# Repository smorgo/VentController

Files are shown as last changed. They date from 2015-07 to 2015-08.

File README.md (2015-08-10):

# VentController
<p>Code and hardware resources for my IoT Vent Controller, intended to control automatic conservatory roof vents (but equally applicable to many similar use cases).</p>
<p>The system is based around the ESP8266 microcontroller. I'm currently using it in its SparkFun ESP8266 Thing guise, but the board could be reworked to suit any of the ESP12-derived boards out there.</p>
<p>You can find the Eagle schematic and board files in the Eagle folder.</p>
<p>Initially, I had intended to use the NodeMCU firmware for the ESP8266. However, that simply takes too much memory and caused immense frustration, so I've moved to using the Arduino IDE and programming in C++. The NodeMCU source files are just here for reference.</p>

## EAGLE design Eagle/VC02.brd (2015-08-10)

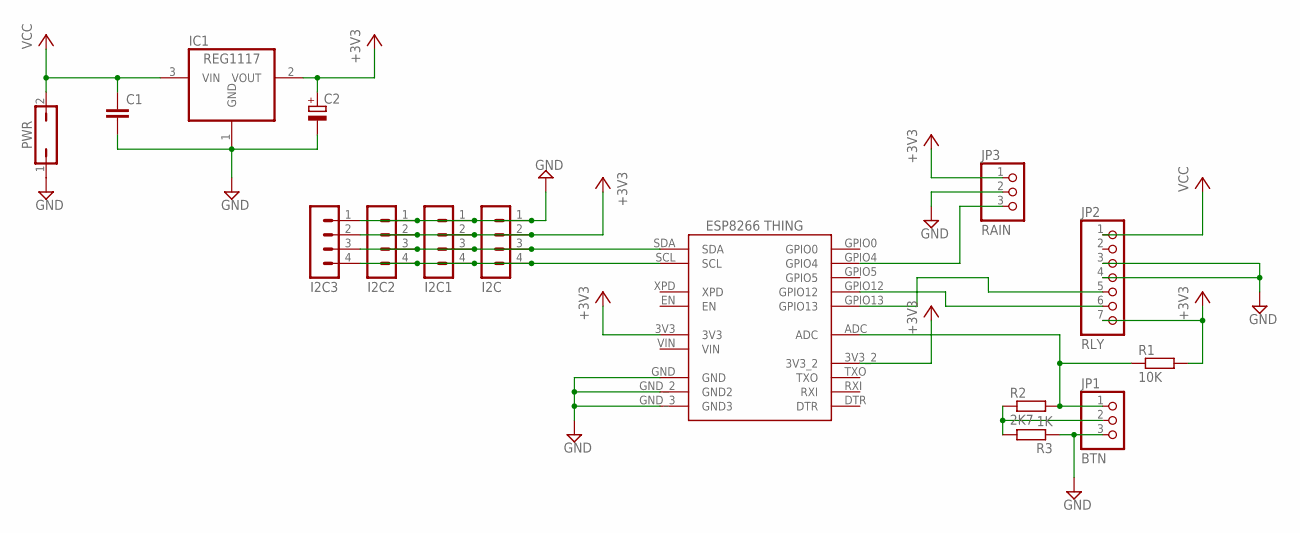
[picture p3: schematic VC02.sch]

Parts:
C1: C-EUC0603K; C0603K; MPN 0603YC104K4T2A
C2: CPOL-EUB; PANASONIC_B; MPN EEEFC1C220AR
I2C, I2C1, I2C2, I2C3: MA04-1
IC1: REG1117; SOT223; MPN LD1117S33TR
JP1: BTN; 1X03
JP2: RLY; 1X07
JP3: RAIN; 1X03
PWR: JP1Q; JP1; MPN 640452-2
R1: 10K; R0805; MPN CRCW080510K0FKEA
R2: 2K7; R0805; MPN CRCW08052K70FKEA
R3: 1K; R0805; MPN CRCW08051K00FKEA
U$1: ESP8266_THING

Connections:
+3V3: C2.+, I2C.2, I2C1.2, I2C2.2, I2C3.2, IC1.2 (VOUT), JP2.7, JP3.1, R1.2, U$1.3V3, U$1.3V3_2
GND: C1.2, C2.-, I2C.1, I2C1.1, I2C2.1, I2C3.1, IC1.1 (GND), JP1.3, JP2.3, JP2.4, JP3.2, PWR.1, R3.1, U$1.GND, U$1.GND_2 (GND2), U$1.GND_3 (GND3)
unnamed: JP2.6, U$1.GPIO12
unnamed: JP2.5, U$1.GPIO13
unnamed: JP3.3, U$1.GPIO4
unnamed: JP1.2, R2.1, R3.2
unnamed: JP1.1, R1.1, R2.2, U$1.ADC
unnamed: I2C.4, I2C1.4, I2C2.4, I2C3.4, U$1.SCL
unnamed: I2C.3, I2C1.3, I2C2.3, I2C3.3, U$1.SDA
VCC: C1.1, IC1.3 (VIN), JP2.1, PWR.2
VIN: U$1.VIN

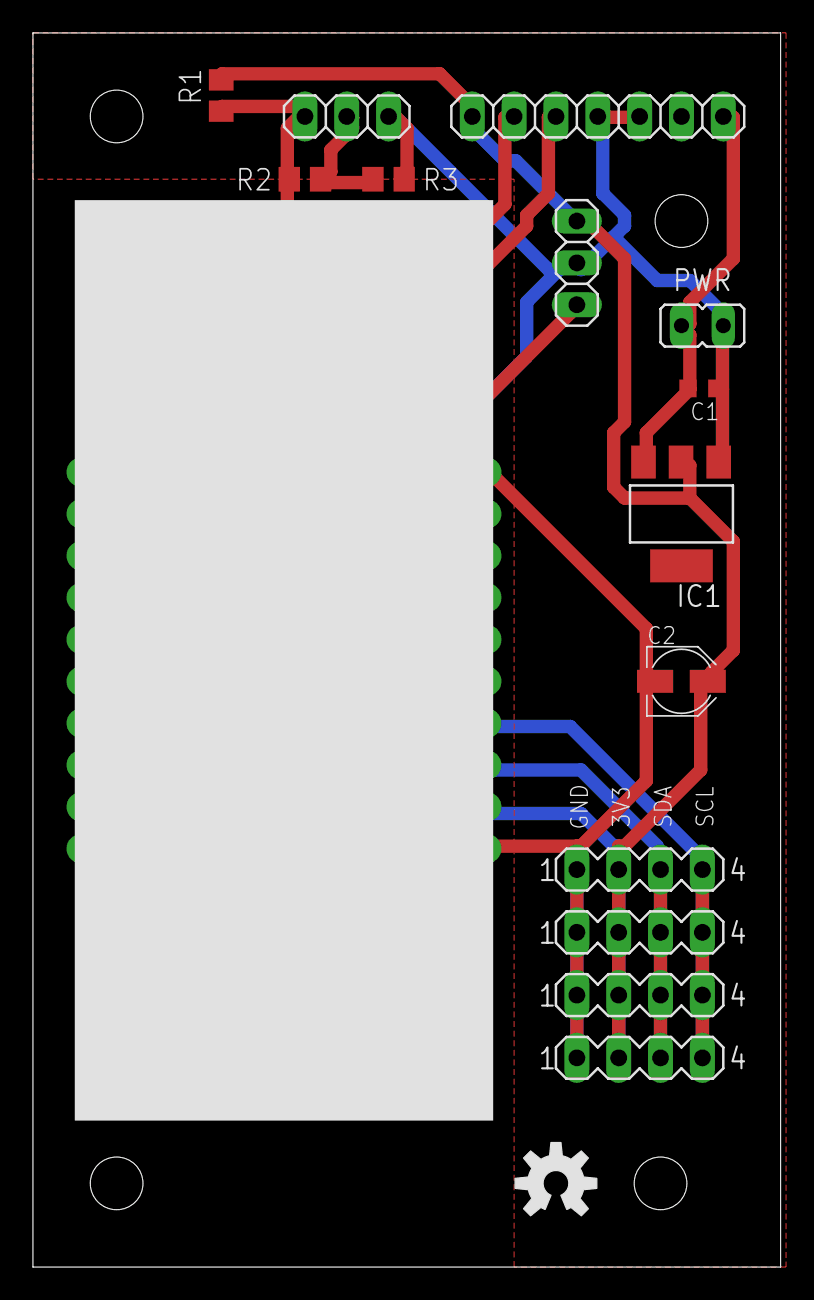
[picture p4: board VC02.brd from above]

Board: 2 copper layers, 45.4 x 74.9 mm, 16 parts (0 on the bottom side), 10 nets.

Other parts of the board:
U$2: OSHW-LOGO-M

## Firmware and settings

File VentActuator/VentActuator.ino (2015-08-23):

/*
 * My keys.h file is loaded from a library, so that these sensitive values
 * are kept outside of the publicly-available code. It should look something
 * like this:
 * 
 * #ifndef __KEYS_H__
 * #define __KEYS_H__
 * #define WIFI_SSID "<Your WiFi SSID>"
 * #define WIFI_PWD "<Your WiFi Passkey>"
 * #define SENSORS_TOPIC "/sensors"
 * #define SENSORS_CMD_TOPIC "/senscmd"
 * #define SERVER "<Your MQTT broker URL or IP address>"
 * #define SENSORS_CLIENT_NAME "SENSORS1"
 * // This secret API_KEY will be shared with other devices that will
 * // publish messages to this device or subscribe to messages from it.
 * // It's used to validate the integrity of the message.
 * #define API_KEY "<32-digit hexadecimal secret key>"
 * #define API_KEY_LENGTH (32)
 * #endif
 */

// Messages received will be processed, even if the hash 
// is incorrect when IS_TEST_MODE is true.
#define IS_TEST_MODE true

#include <keys.h>
#include <MD5.h>
#include <MQTT.h>
#include <PubSubClient.h>

#include <ESP8266WiFi.h>
#include <Wire.h>


// MQTT Topics
const char TOPIC_CMD[] ="/cmd";
const char TOPIC_STATUS[] = "/status";
const char TOPIC_EVENT[] = "/event";

// Message Types
#define MSG_TYPE_SURVEY (1)
#define MSG_TYPE_HELLO (2)
#define MSG_TYPE_SENSOR (3)
#define MSG_TYPE_ACTUATOR (4)
#define MSG_TYPE_ACTSTAT (5)
#define MSG_TYPE_RESET (6)
#define MSG_TYPE_OVERRIDE (7)
#define MSG_TYPE_BUTTON (8)

//////////////////////
// WiFi Definitions //
//////////////////////
const char ssid[] = WIFI_SSID;
const char password[] = WIFI_PWD;
const char server[] = SERVER;
const char clientName[] = ACTUATOR_CLIENT_NAME;
const char apiKey[] = API_KEY;
const int apiKeyLength = API_KEY_LENGTH;
String privateCmdTopic;

#pragma message("ssid: " WIFI_SSID)
#pragma message("server: " SERVER)
#pragma message("clientName: " ACTUATOR_CLIENT_NAME)
#pragma message("apiKey: " API_KEY)

WiFiClient wifiClient;
PubSubClient client(wifiClient, server, 1883);
bool seeded = false;

/////////////////////
// Pin Definitions //
/////////////////////
const int LED_PIN = 5; // Thing's onboard, green LED
const int RAIN_PIN = 4;
const int BUTTON_PIN = A0; 
const int MOTOR_OPEN_PIN = 12;
const int MOTOR_CLOSE_PIN = 13;

/////////////////
// Post Timing //
/////////////////
const unsigned long postRate = 15000;
unsigned long lastPost = 0;
unsigned long counter = 0;

/////////////////
// State       //
/////////////////
const int VENT_CLOSED = 0;
const int VENT_OPEN = 4;
const int NONE = -1;
const int fullTransitTime = 8000; // 8 seconds
const int stepTransitTime = fullTransitTime / VENT_OPEN;
const int WET = 0;
const int DRY = 1;
const int BTN_NONE = 0;
const int BTN_1 = 1;
const int BTN_2 = 2;
const int BTN_BOTH = 3;

// Button thresholds
const int BUTTON_HIGH_THRESHOLD = 840;
const int BUTTON1_HIGH_THRESHOLD = 520;
const int BUTTON2_HIGH_THRESHOLD = 150;

int currentPosition = VENT_OPEN; // On boot, we'll assume it's open and close it.
int targetPosition = NONE;
int newPosition = NONE; // If it's raining, this is zero, otherwise, it's targetPosition
int buttonState = NONE;
int rainState = NONE;
int rainStateCounter = 0;
int previousRainState = NONE;
int previousButtonState = NONE;
int buttonStateCounter = 0;

unsigned long startMillis = 0; // When the current movement started
unsigned long endMillis = 0; // When the current movement should end

bool isMoving = false;
bool directionOpen = false;
bool currentOpenRelayState = HIGH;
bool currentCloseRelayState = HIGH;
bool ignoreRainSensor = false;

String getParam(String msg, String name)
{
  String tmpMsg = "," + msg;
  String lookFor = "," + name + "(";

  int startIx = tmpMsg.indexOf(lookFor);
  if(startIx < 0)
  {
    return "";
  }
  int endIx = tmpMsg.indexOf(")", startIx);
  if(endIx < startIx)
  {
    return "";
  }
  String val =  msg.substring(startIx + lookFor.length()-1, endIx-1);
  Serial.print("Looked for ");
  Serial.print(lookFor);
  Serial.print(" found ");
  Serial.println(val);

  return val;
}

String getHash(String payload)
{
  int payloadLength = payload.length();
  int bufferLength = apiKeyLength + payloadLength + 1;
  char *buffer = (char *)malloc(bufferLength);
  memcpy(buffer, apiKey, apiKeyLength);
  payload.toCharArray(buffer + apiKeyLength, payloadLength + 1);
  
  unsigned char* hash=MD5::make_hash(buffer);
  char *md5str = MD5::make_digest(hash, 16);
  String calcHash = String(md5str);
  free(md5str);
  free(hash);
  free(buffer);

  return calcHash;
}

void processPositionMessage(String msg)
{
  int pos = getParam(msg,"TPOS").toInt();

  Serial.print("Position requested: ");
  Serial.println(pos);
  
  setPosition(pos);
}

bool isMyTopic(String topic)
{
  return (topic == TOPIC_CMD) ||
         (topic == privateCmdTopic);
}

void processMessage(String recv_topic, String msg)
{
  Serial.print(recv_topic);
  Serial.print(" => ");
  Serial.println(msg);

  if(!isMyTopic(recv_topic))
  {
    return;
  }
  
  int msgType = getParam(msg,"M").toInt();

  switch(msgType)
  {
    case MSG_TYPE_SURVEY:
      publish(TOPIC_STATUS,getHelloMessage());
      break;
    case MSG_TYPE_RESET:
      Serial.println("Restarting...");
      delay(1000);
      ESP.restart();
      break;
    case MSG_TYPE_ACTUATOR:
      processPositionMessage(msg);
      break;
    default:
      Serial.println("Unrecognised message");
  }
}

String getValidMessage(String msg)
{
 int delimIx = msg.indexOf(':');

  if(delimIx < 0 || delimIx == (msg.length() - 1))
  {
    // No hash
    return IS_TEST_MODE ? msg : String();
  }

  String payload = msg.substring(0,delimIx);
  String payloadHash = msg.substring(delimIx + 1);

  String calcHash = getHash(payload);
    
  if(calcHash.equalsIgnoreCase(payloadHash))
  {
    Serial.println("HASH MATCH");
    return payload;    
  }

  Serial.println("**HASH DOESN'T MATCH**");
  if(IS_TEST_MODE)
  {
    Serial.print("Received ");
    Serial.println(payloadHash);
    Serial.print("Calculated ");
    Serial.println(calcHash);
    return payload;
  }

  return String();
}

void subscribe(String topic)
{
  Serial.print("Subscribing to MQTT topic: ");
  Serial.println(topic);
  client.subscribe(topic);
}

void publishToConnection(String topic, String msg)
{
  String calcHash = getHash(msg);
  
  msg += ":";
  msg += calcHash;

  Serial.print("[");
  Serial.print(++counter);
  Serial.print("] ");
  Serial.print("Publish to ");
  Serial.print(topic);
  Serial.print(" = ");
  Serial.println(msg);
  
  if(!client.publish(topic, msg))
  {
    Serial.println("Publish FAILED");
  } 
}

void publish(String topic, String msg)
{
  bool connected = client.connected();

  if(!connected) 
  {
    connected = connectBroker();
  }
  
  if(connected)
  {
    publishToConnection(topic, msg);
  }
}

String getBaseMessage(int messageType)
{
  // Add a random value to our message, so that the MD5 hash will be different,
  // even when all of the sensor readings are the same.
  if(!seeded)
  {
    randomSeed(millis());
    seeded = true;
  }
  
  long rand = random(2147483647);
  
  String msg = "R(" + String(rand) + "),M(" + String(messageType) + "),DEV(" + clientName + ")";

  return msg;
}

String getHelloMessage()
{
  String msg = getBaseMessage(MSG_TYPE_HELLO);

  // Add Topics
  msg += ",PUB(" + String(TOPIC_STATUS) + ")" +
         ",SUB(" + String(TOPIC_CMD) + ")" +
         ",SUB(" + privateCmdTopic + ")";

  return msg;
}

String getActStatMessage()
{
  String msg = getBaseMessage(MSG_TYPE_ACTSTAT);

  String msg2 = ",POS(" + String(currentPosition) + "),TPOS(" + String(targetPosition) + "),BN(" + String(buttonState) + "),RA(" + String(rainState) + ")";

  return msg + msg2;
}

String getButtonMessage()
{
  String msg = getBaseMessage(MSG_TYPE_BUTTON);

  String msg2 = ",BN(" + String(buttonState) + ")";

  return msg + msg2;
}

bool connectBroker()
{
  Serial.println("Connecting to MQTT broker");
  if (client.connect(clientName)) 
  {
    Serial.println("Connected to MQTT broker");
    subscribe(TOPIC_CMD);
    subscribe(privateCmdTopic);
    publishToConnection(TOPIC_STATUS,getHelloMessage());
    return true;
  }    
  else 
  {
    Serial.println("MQTT connect failed");
    Serial.println("Will reset and try again...");
    return false;
  }
}

void connectWiFi()
{
  byte ledStatus = LOW;

  Serial.println("Connecting to WiFi");
  // Set WiFi mode to station (as opposed to AP or AP_STA)
  WiFi.mode(WIFI_STA);

  // WiFI.begin([ssid], [passkey]) initiates a WiFI connection
  // to the stated [ssid], using the [passkey] as a WPA, WPA2,
  // or WEP passphrase.
  WiFi.begin(ssid, password);

  // Use the WiFi.status() function to check if the ESP8266
  // is connected to a WiFi network.
  while (WiFi.status() != WL_CONNECTED)
  {
    // Blink the LED
    digitalWrite(LED_PIN, ledStatus); // Write LED high/low
    ledStatus = (ledStatus == HIGH) ? LOW : HIGH;

    // Delays allow the ESP8266 to perform critical tasks
    // defined outside of the sketch. These tasks include
    // setting up, and maintaining, a WiFi connection.
    delay(100);
    // Potentially infinite loops are generally dangerous.
    // Add delays -- allowing the processor to perform other
    // tasks -- wherever possible.
  }
  Serial.println("Connected to WiFi");

  connectBroker();
}

void initHardware()
{
  Serial.begin(9600);
  Serial.println("");
  pinMode(LED_PIN, OUTPUT);
  pinMode(MOTOR_OPEN_PIN, OUTPUT);
  pinMode(MOTOR_CLOSE_PIN, OUTPUT);
  pinMode(RAIN_PIN, INPUT_PULLUP);
  pinMode(BUTTON_PIN, INPUT);
  digitalWrite(LED_PIN, LOW);
  digitalWrite(MOTOR_OPEN_PIN, HIGH);
  digitalWrite(MOTOR_CLOSE_PIN, HIGH);
  Serial.println("");
}

int postStatus()
{
  // LED turns on when we enter, it'll go off when we 
  // successfully post.
  digitalWrite(LED_PIN, HIGH);

  if(IS_TEST_MODE) Serial.println("Publishing status");
   
  if(WiFi.status() != WL_CONNECTED)
  {
    connectWiFi();
  }

  publish(TOPIC_STATUS,getActStatMessage());

  // Before we exit, turn the LED off.
  digitalWrite(LED_PIN, LOW);

  if(IS_TEST_MODE) Serial.println("Done publishing update");
  return 1; // Return success
}

void callback(const MQTT::Publish& pub) 
{
  String msg = getValidMessage(pub.payload_string());

  if(msg.length() > 0)
  {
    processMessage(pub.topic(), msg);
  }
}

void setOpenRelay(bool state)
{
  if(state != currentOpenRelayState)
  {
    Serial.print("Open relay = ");
    Serial.println(state ? "OFF" : "ON");
    digitalWrite(MOTOR_OPEN_PIN, state);
    currentOpenRelayState = state;  
  }
}

void setCloseRelay(bool state)
{
  if(state != currentCloseRelayState)
  {
    Serial.print("Close relay = ");
    Serial.println(state ? "OFF" : "ON");
    digitalWrite(MOTOR_CLOSE_PIN, state);
    currentCloseRelayState = state;  
  }
}

void setRelays()
{
  if(!isMoving)
  {
    // Nothing to do
    return;
  }
  
  if(millis() > endMillis)
  {
    Serial.println("Stopping");
    // Time to stop
    setOpenRelay(HIGH);
    setCloseRelay(HIGH);
    isMoving = false;
    directionOpen = false;
    startMillis = 0;
    endMillis = 0;
    currentPosition = newPosition;
  }
  else
  {
    setOpenRelay(directionOpen ? LOW : HIGH);
    setCloseRelay(directionOpen ? HIGH : LOW);
  }
}

void setPosition(int position)
{
  if(isMoving)
  {
    return;  
  }
  
  targetPosition = position;
  
  if(rainState == WET && !ignoreRainSensor)
  {
    newPosition = 0;
  }
  else
  {
    newPosition = targetPosition;
  }

  Serial.print("Selecting position ");
  Serial.println(String(newPosition));
  
  int steps = abs(newPosition - currentPosition);

  if(steps == 0)
  {
    // Nowhere to go
    return;
  }

  startMillis = millis();
  endMillis = startMillis + steps * stepTransitTime;
  directionOpen = (newPosition > currentPosition);
  isMoving = true;

  Serial.print("Timers: startMillis = ");
  Serial.print(String(startMillis));
  Serial.print(" endMillis = ");
  Serial.println(String(endMillis));
  
  setRelays();
}

void setup() 
{
  privateCmdTopic = String(TOPIC_CMD) + "/" + String(ACTUATOR_CLIENT_NAME);
  
  initHardware();

  client.set_callback(callback);
  
  connectWiFi();

  setPosition(VENT_CLOSED);
  digitalWrite(LED_PIN, HIGH);
}

void checkRain()
{
  int rain = digitalRead(RAIN_PIN) == LOW ? WET : DRY;

  // Allow the pin to settle
  if(rain != previousRainState)
  {
    previousRainState = rain;
    rainStateCounter = 0;
    return;
  }

  if(++rainStateCounter > 50)
  {
    if(rain != rainState)
    {
      Serial.println(rain == WET ? "It's RAINING" : "It's DRY");
      rainState = rain;
      setPosition(targetPosition); // This will either cause the vent to close if it's raining, or move to its target position if it's not
    }
    rainStateCounter = 0;
  }
}

void checkButtons()
{
  int btn = analogRead(BUTTON_PIN);

//  Serial.print("Button pin: ");
//  Serial.println(btn);

  int btn_state = (btn > BUTTON_HIGH_THRESHOLD) ? BTN_NONE :
                  (btn > BUTTON1_HIGH_THRESHOLD) ? BTN_1 :
                  (btn > BUTTON2_HIGH_THRESHOLD) ? BTN_2 :
                  BTN_BOTH;   

  if(btn_state != previousButtonState)
  {
      previousButtonState = btn_state;
      buttonStateCounter = 0;
      return;
  }

  if(++buttonStateCounter > 10)
  {
    if(btn_state != buttonState)
    {
      Serial.print("Button state: ");
      Serial.println(btn_state);
      buttonState = btn_state;
      publish(TOPIC_EVENT,getButtonMessage());
    }
    buttonStateCounter = 0;
  }
}

void loop() 
{
  checkRain();
  checkButtons();
  
  setRelays();
  client.loop();
  if (lastPost + postRate <= millis())
  {
    if (postStatus())
    {
      lastPost = millis();
    }
  }

  delay(100);    
}

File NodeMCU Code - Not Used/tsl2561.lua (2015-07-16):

-- Library for working with TSL2561 I2C Luminosity sensor
-- As used on breakout board by Adafruit
-- Special hat-tip to lady ada - hacker hero - amongst many others
-- This code is AGPL v3 by gareth@l0l.org.uk and Hamish Cunningham
-- blah blah blah standard licence conditions apply blah blah blah
-- Adapted by Aeprox@github for use in ESPlogger

local i2cutils = require("i2cutils") -- get our helper functions loaded

local moduleName = "tsl2561"
-- the package table, and lots of constants
local M = {
    TSL2561_ADDR_FLOAT            = 0x39,
    TSL2561_COMMAND_BIT           = 0x80,   -- Must be 1
    TSL2561_CONTROL_POWERON       = 0x03,
    TSL2561_CONTROL_POWEROFF      = 0x00,
    TSL2561_REGISTER_CONTROL      = 0x00,
    TSL2561_REGISTER_TIMING       = 0x01,
    TSL2561_REGISTER_ID           = 0x0A,
    TSL2561_REGISTER_CHAN0_LOW    = 0x0C,
    TSL2561_REGISTER_CHAN0_HIGH   = 0x0D,
    TSL2561_REGISTER_CHAN1_LOW    = 0x0E,
    TSL2561_REGISTER_CHAN1_HIGH   = 0x0F,
    
    TSL2561_INTEGRATIONTIME_13MS  = 0x00,   -- 13.7ms
    TSL2561_INTEGRATIONTIME_101MS = 0x01,   -- 101ms
    TSL2561_INTEGRATIONTIME_402MS = 0x02,   -- 402ms
    
    TSL2561_GAIN_0X               = 0x00,   -- No gain
    TSL2561_GAIN_16X              = 0x10,   -- 16x gain
}
_G[moduleName] = M

local busid = 0 -- i2c bus id

-- add a few recursive definitions
local function enable(dev_addr) -- enable the device
  i2cutils.write_reg(
    dev_addr,
    bit.bor(M.TSL2561_COMMAND_BIT, M.TSL2561_REGISTER_CONTROL),
    M.TSL2561_CONTROL_POWERON
  )
end
local function disable(dev_addr) -- disable the device
  i2cutils.write_reg(
    dev_addr,
    bit.bor(M.TSL2561_COMMAND_BIT, M.TSL2561_REGISTER_CONTROL),
    M.TSL2561_CONTROL_POWEROFF
  )
end
local function settimegain(dev_addr, time, gain) -- set the integration time and gain together
  i2cutils.write_reg(
    dev_addr,
    bit.bor(M.TSL2561_COMMAND_BIT, M.TSL2561_REGISTER_TIMING),
    bit.bor(time, gain)
  )
end
local function getFullLuminosity(dev_addr) -- Do the actual reading from the sensor
  local ch0low = i2cutils.read_reg(
    dev_addr,
    bit.bor(M.TSL2561_COMMAND_BIT, M.TSL2561_REGISTER_CHAN0_LOW)
  )
  local ch0high = i2cutils.read_reg(
    dev_addr,
    bit.bor(M.TSL2561_COMMAND_BIT, M.TSL2561_REGISTER_CHAN0_HIGH)
  )
  ch0=string.byte(ch0low)+(string.byte(ch0high)*256)

  local ch1low = i2cutils.read_reg(
    dev_addr,
    bit.bor(M.TSL2561_COMMAND_BIT, M.TSL2561_REGISTER_CHAN1_LOW)
  )
  local ch1high = i2cutils.read_reg(
    dev_addr,
    bit.bor(M.TSL2561_COMMAND_BIT, M.TSL2561_REGISTER_CHAN1_HIGH)
  )
  ch1=string.byte(ch1low)+(string.byte(ch1high)*256)
  return ch0, ch1
end
function M.getchannels()
  dev_addr = M.TSL2561_ADDR_FLOAT
  i2c.setup(busid, sda , scl, i2c.SLOW)
  result = i2cutils.read_reg(
    dev_addr,
    bit.bor(M.TSL2561_COMMAND_BIT, M.TSL2561_REGISTER_ID)
  )
  enable(dev_addr)
  settimegain(dev_addr, M.TSL2561_INTEGRATIONTIME_402MS, M.TSL2561_GAIN_16X)
  disable(dev_addr)
  tmr.delay(1000) -- give 1ms for sensor to settle
  enable(dev_addr)
  tmr.delay(500000) -- gives 500ms for integration time
  ch0,ch1 = getFullLuminosity(dev_addr)
  disable(dev_addr)
  return ch0, ch1
end

return M

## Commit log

2015-07-16 Initial sensor code
2015-08-06 Moved to Arduino sketch
2015-08-10 Sketch update
    Sensor code working. First version of actuator code added.
2015-08-10 Added boards and renamed NodeMCU files
    [VC02.brd, VC02.sch]
2015-08-13 Added vent relay control
    Vent relay now operates on boot to ensure that vents are closed. Also
    responds to message over MQTT to set vent position, though message
    format needs updating.
2015-08-23 Updated message formats & added Xamarin client
    [MQTT Messages.xlsx]

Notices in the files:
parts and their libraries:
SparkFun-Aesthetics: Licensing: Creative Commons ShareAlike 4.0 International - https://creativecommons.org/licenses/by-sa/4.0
